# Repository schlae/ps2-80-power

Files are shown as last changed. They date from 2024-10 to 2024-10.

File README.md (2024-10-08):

# IBM PS/2 Model 80 Power Supply Schematics

There are multiple types of power supplies for these machines. This one is for the one marked 72X6665 / PEC 3978. This is the red switch 225W model.

## Notes

The design is an LLC resonant converter. It has a rather interesting auxiliary bias supply to power the PWM controller, so technically it is two supplies in one box.

* Inrush current into the main reservoir capacitors is limited by R117/118 and RT1/RT2. The capacitors are tied in series (to handle the 220V input case) with balancing resistors.
* The bias supply uses a preregulator that detects ~180V Vp-p and, partway through every AC cycle, cuts off a triac connected in series with a plain-old linear transformer isolated power supply. This ensures that the VCC bias supply has roughly the same voltage regardless of whether it is connected to 120V or 220V.
* The PWM controller is a SG3524 with external transistors that drive an isolation transformer in order to control the BJTs in the main power stage on the non-isolated side. The output voltage trim is set by R77, which samples both the +5V and +12V rail.
* An overcurrent comparator monitors the ripple current through the main power transformer and latches off the PWM controller if it exceeds a threshold. It also monitors the current *difference* between the two Schottky diodes in the 12V secondary side, presumably to detect Schottky diode failures.
* Every voltage (+12, -12V, +5V) is monitored for overvoltage and undervoltage. Overvoltages cause the supply to latch off. Undervoltage just deasserts the power good. Trimmer potentiometer R50 adjusts the voltage reference used by the comparators.
* The power LED is driven by the power good signal.
* The HDD LED is driven by a signal from the planar (motherboard).

## License
This work is licensed under Creative Commons Attribution-ShareAlike 4.0 International.
(C) 2024 Tube Time.

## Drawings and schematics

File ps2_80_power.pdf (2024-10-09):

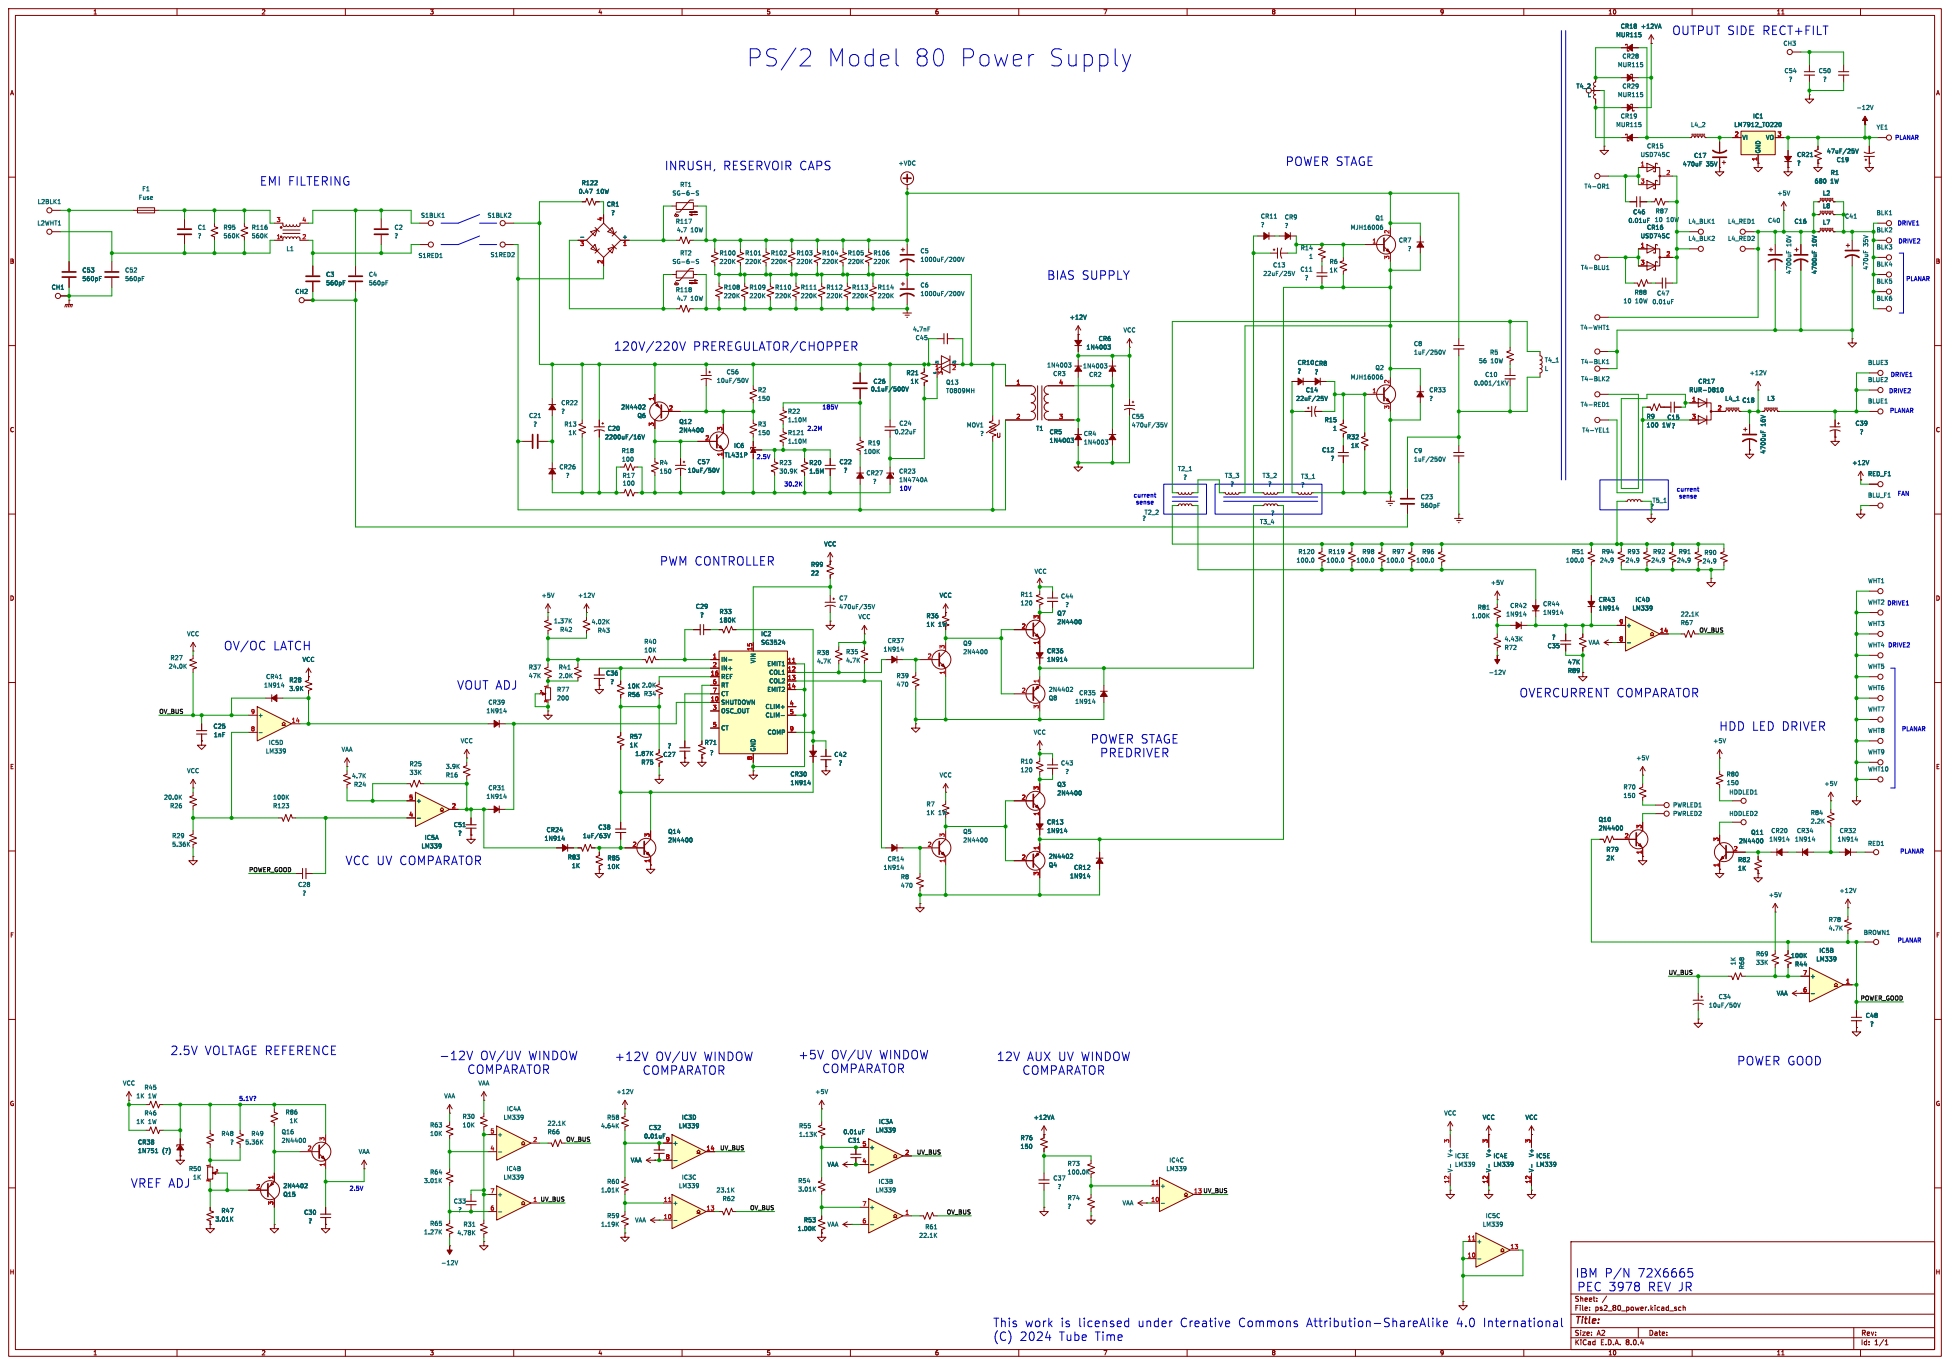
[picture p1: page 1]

OUTPUT SIDE RECT+FILT

PLANAR PS/2 Model 80 Power Supply

current sense POWER STAGE

current sense OVERCURRENT COMPARATOR VOUT ADJ

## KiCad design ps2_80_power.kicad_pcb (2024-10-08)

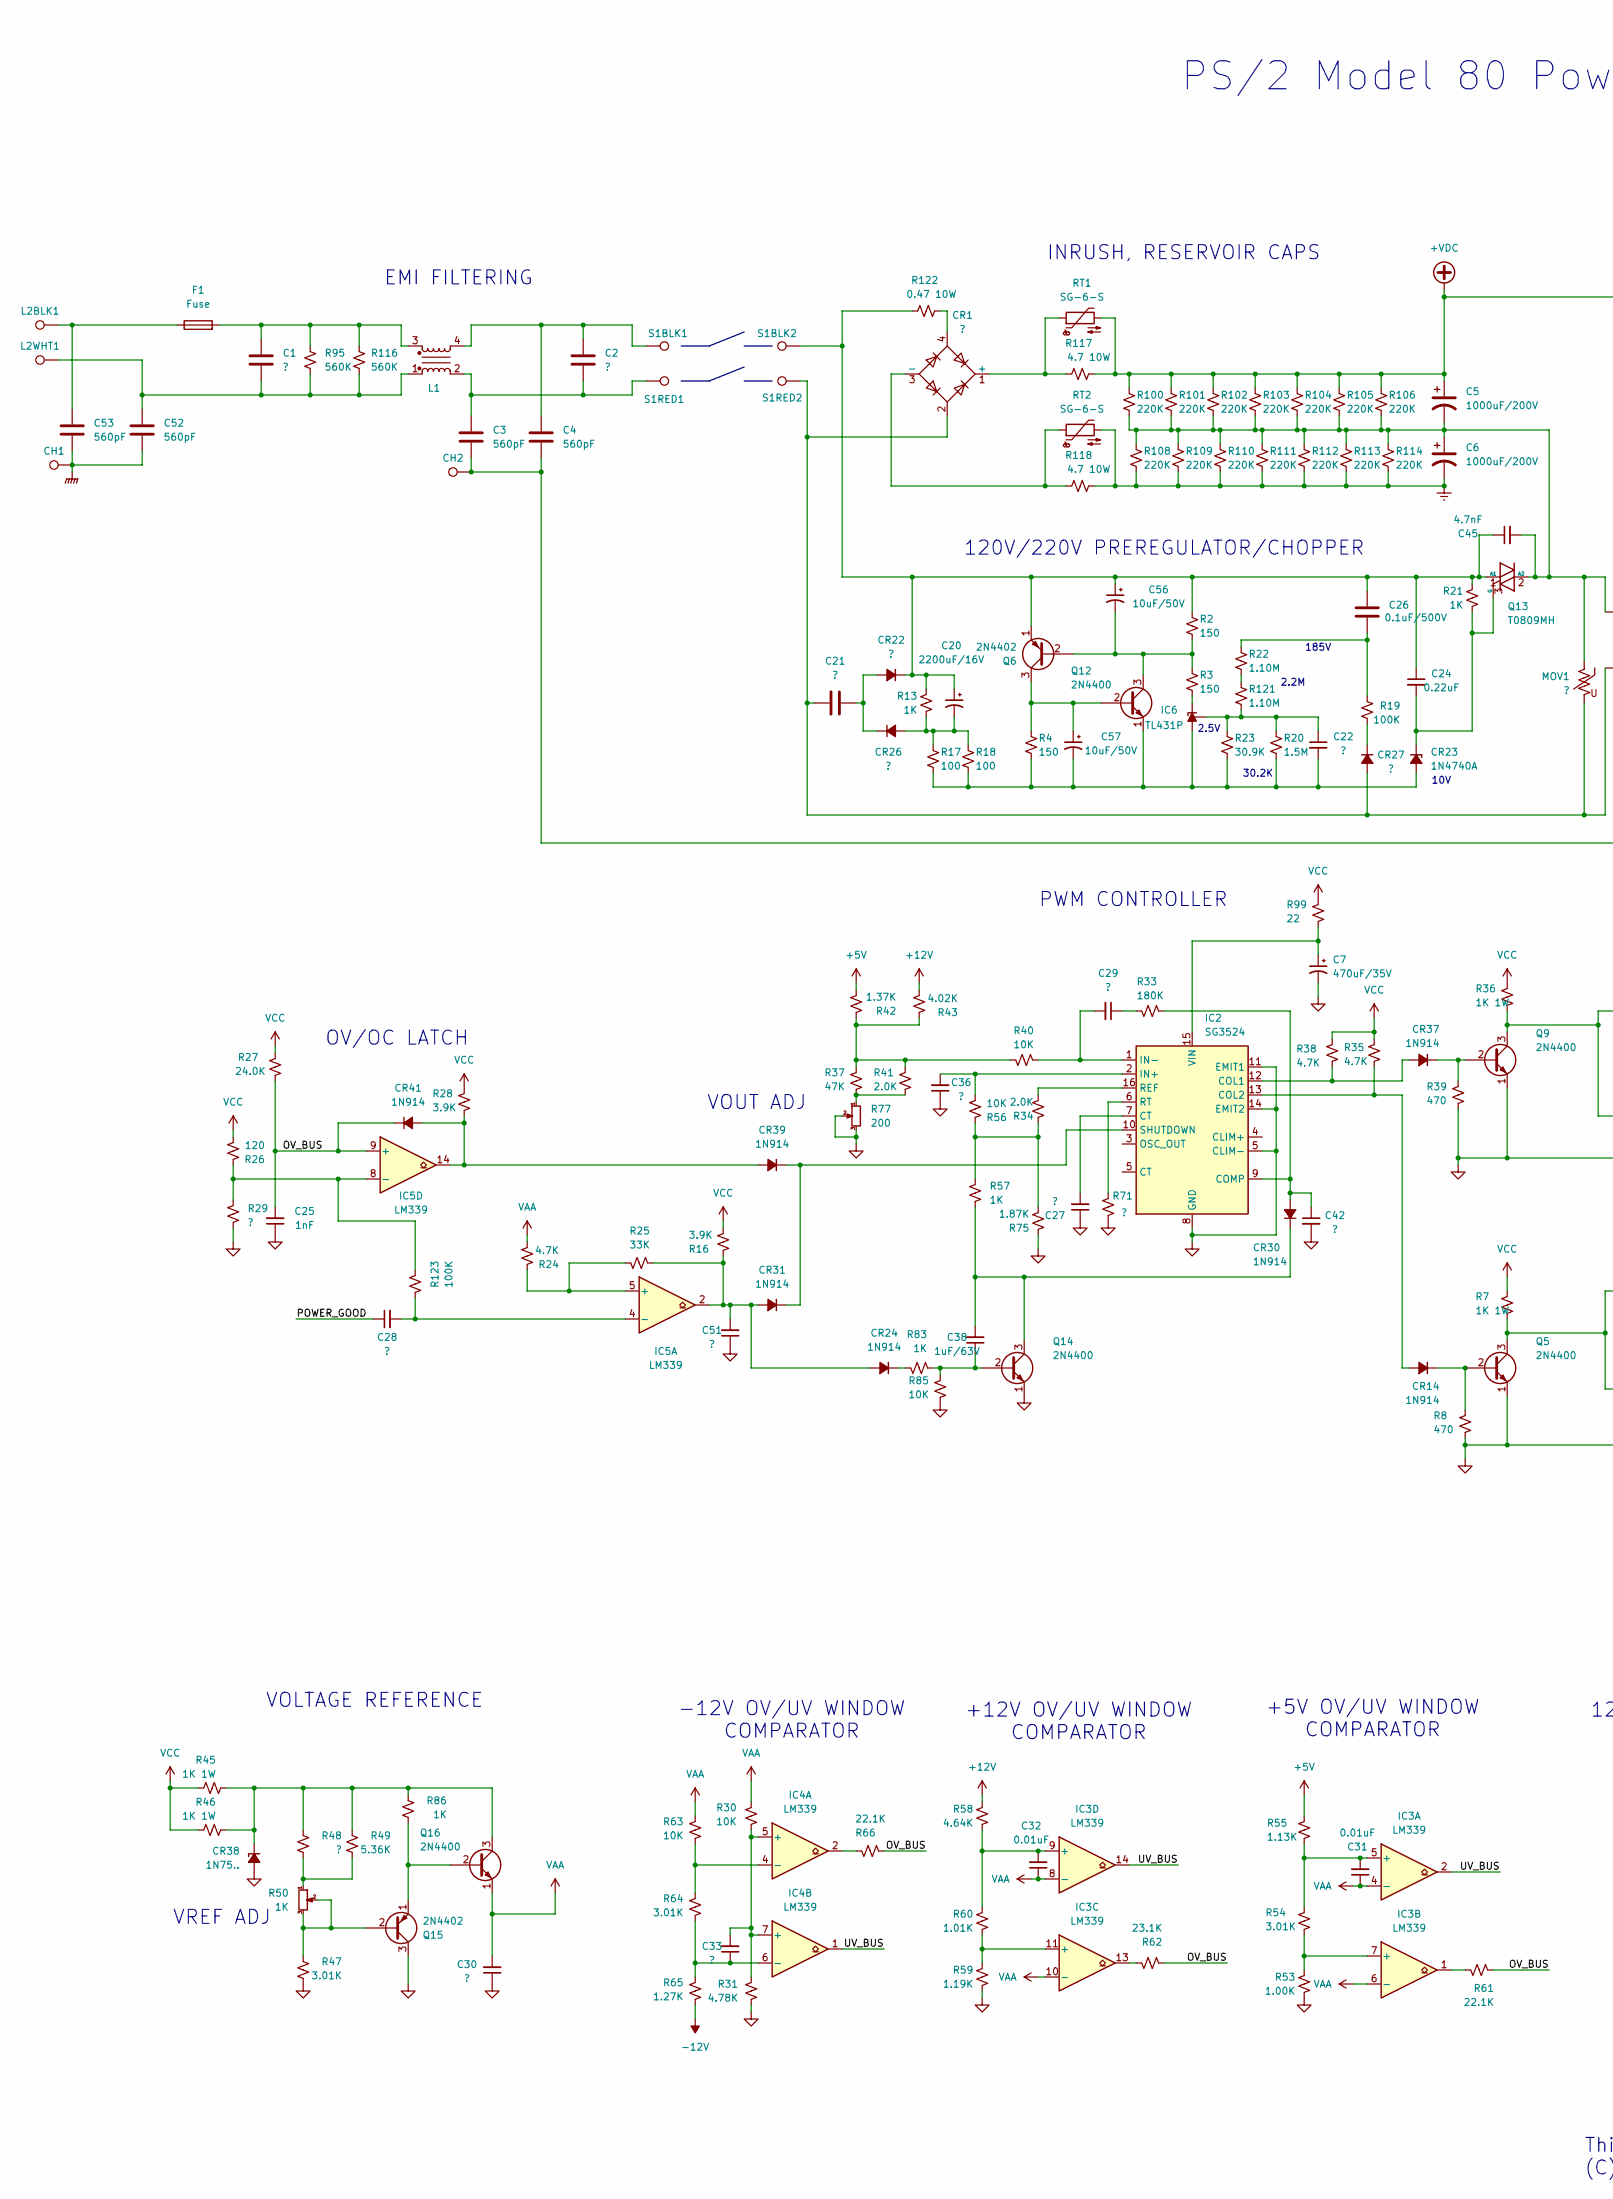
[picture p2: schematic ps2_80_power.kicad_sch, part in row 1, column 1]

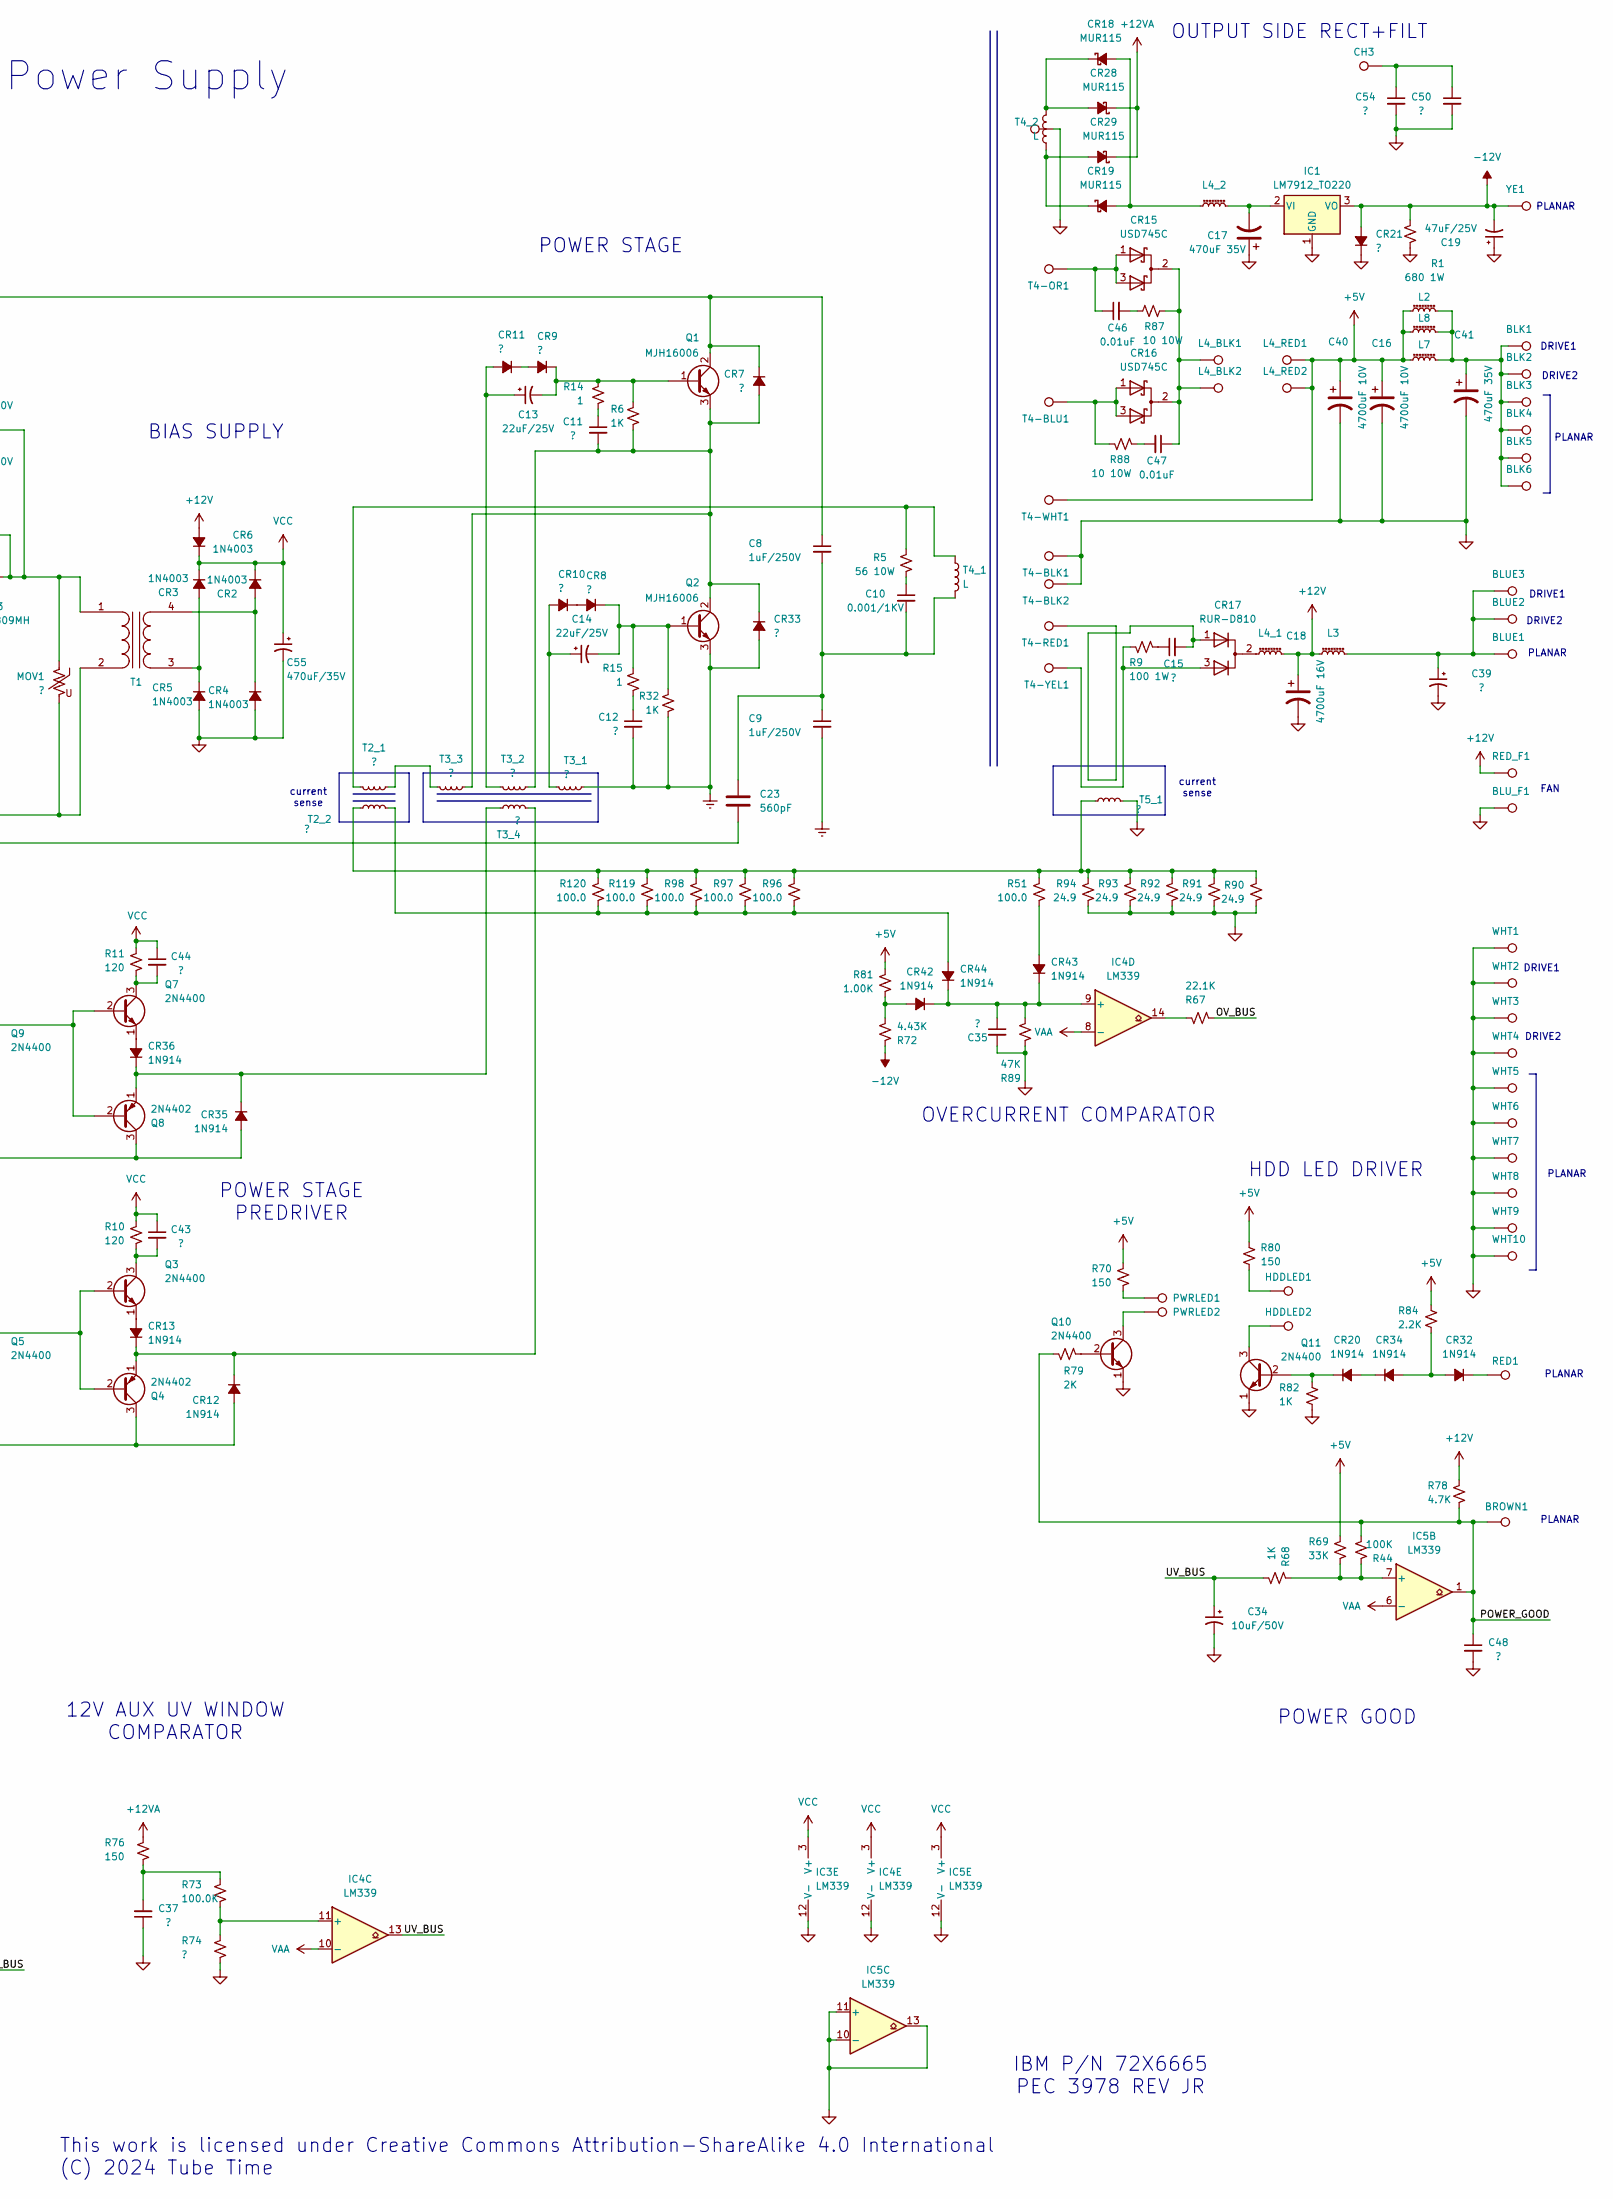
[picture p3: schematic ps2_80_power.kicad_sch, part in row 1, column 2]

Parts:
BLK1, BLK2, BLK3, BLK4, BLK5, BLK6: TestPoint; SolderWire-1sqmm_1x01_D1.4mm_OD2.7mm
BLUE1, BLUE2, BLUE3: TestPoint; SolderWire-1sqmm_1x01_D1.4mm_OD2.7mm
BLU_F1: TestPoint; SolderWire-1sqmm_1x01_D1.4mm_OD2.7mm
BROWN1: TestPoint; SolderWire-1sqmm_1x01_D1.4mm_OD2.7mm
C1, C2, C21: ?; C_Rect_L29.0mm_W12.2mm_P27.50mm_MKT
C3, C4, C23, C52, C53: 560pF; C_Disc_D12.5mm_W5.0mm_P10.00mm
C5, C6: 1000uF/200V; CP_Radial_D35.0mm_P10.00mm_SnapIn
C7, C55: 470uF/35V; CP_Radial_D13.0mm_P5.00mm
C8, C9: 1uF/250V; C_Rect_L29.0mm_W7.6mm_P27.50mm_MKT
C10: 0.001/1KV; C_Disc_D7.5mm_W5.0mm_P7.50mm
C11, C12, C22, C27, C28, C36: ?; C_Axial_L3.8mm_D2.6mm_P12.50mm_Horizontal
C13, C14: 22uF/25V; CP_Radial_D5.0mm_P2.50mm
C15, C48: ?; C_Disc_D10.5mm_W5.0mm_P7.50mm
C16, C40: 4700uF 10V; CP_Radial_D16.0mm_P7.50mm
C17, C41: 470uF 35V; CP_Radial_D13.0mm_P7.50mm
C18: 4700uF 16V; CP_Radial_D16.0mm_P7.50mm
C19: 47uF/25V; CP_Radial_D5.0mm_P2.50mm
C20: 2200uF/16V; CP_Radial_D16.0mm_P7.50mm
C24: 0.22uF; C_Axial_L3.8mm_D2.6mm_P12.50mm_Horizontal
C25: 1nF; C_Axial_L3.8mm_D2.6mm_P10.00mm_Horizontal
C26: 0.1uF/500V; C_Rect_L11.0mm_W2.8mm_P10.00mm_MKT
C29, C30, C33, C35, C37, C42, C43, C44, C51: ?; C_Axial_L3.8mm_D2.6mm_P10.00mm_Horizontal
C31, C32: 0.01uF; C_Axial_L3.8mm_D2.6mm_P7.50mm_Horizontal
C34, C56, C57: 10uF/50V; CP_Radial_D5.0mm_P2.50mm
C38: 1uF/63V; C_Rect_L7.0mm_W6.0mm_P5.00mm
C39: ?; CP_Radial_D5.0mm_P2.50mm
C45: 4.7nF; C_Axial_L3.8mm_D2.6mm_P10.00mm_Horizontal
C46, C47: 0.01uF; C_Disc_D10.5mm_W5.0mm_P7.50mm
C50: ?; C_Rect_L11.0mm_W2.8mm_P10.00mm_MKT
C54: ?; C_Disc_D7.5mm_W5.0mm_P7.50mm
CH1, CH2, CH3: TestPoint; SolderWire-2.5sqmm_1x01_D2.4mm_OD3.6mm
CR1: ?; Diode_Bridge_Vishay_KBPC1
CR2, CR3, CR4, CR5, CR6: 1N4003; D_DO-41_SOD81_P12.70mm_Horizontal
CR7, CR8, CR9, CR10, CR11, CR22, CR26, CR27, CR33: ?; D_DO-41_SOD81_P12.70mm_Horizontal
CR12, CR13, CR14, CR20, CR24, CR30, CR31, CR32, CR34, CR35, CR36, CR37, CR39, CR41, CR42, CR43, CR44: 1N914; D_DO-41_SOD81_P12.70mm_Horizontal
CR15, CR16: USD745C; TO-220-3_Vertical
CR17: RUR-D810; TO-220-3_Vertical
CR18, CR19, CR28, CR29: MUR115; D_DO-41_SOD81_P10.16mm_Horizontal
CR21: ?; D_DO-201_P15.24mm_Horizontal
CR23: 1N4740A; D_DO-41_SOD81_P12.70mm_Horizontal
CR38: 1N75..; D_DO-41_SOD81_P10.16mm_Horizontal
F1: Fuse; Fuseholder_Clip-6.3x32mm_Littelfuse_102_122_Inline_P34.21x7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
HDDLED1, HDDLED2: TestPoint; SolderWire-0.1sqmm_1x01_D0.4mm_OD1mm
IC1: LM7912_TO220; TO-220-3_Vertical
IC2: SG3524; DIP254P762X635-16
IC3, IC4, IC5: LM339; DIP254P762X635-14
IC6: TL431P; DIP-8_W7.62mm
L1: Choke_Schaffner_RN102-0.3-02-22M; Choke_Schaffner_RN102-04-14.0x14.0mm
L2, L3, L7, L8: L_Ferrite_Small; L_Axial_L11.0mm_D4.5mm_P7.62mm_Vertical_Fastron_MECC
L2BLK1, L2WHT1, L4_BLK1, L4_BLK2, L4_RED1, L4_RED2: TestPoint; SolderWire-2.5sqmm_1x01_D2.4mm_OD3.6mm
L4_1, L4_2: L_Ferrite_Small; L_Axial_L29.9mm_D14.0mm_P38.00mm_Horizontal_Vishay_IHA-105
MOV1: ?; RV_Disc_D21.5mm_W4.3mm_P10mm
PWRLED1, PWRLED2: TestPoint; SolderWire-0.1sqmm_1x01_D0.4mm_OD1mm
Q1, Q2: MJH16006; TO-247-3_Vertical
Q3, Q5, Q7, Q9, Q10, Q14, Q16: 2N4400; TO-92_Inline
Q4, Q8, Q15: 2N4402; TO-92_Inline
Q6: 2N4402; TO-92_Inline_Wide
Q11, Q12: 2N4400; TO-92_Inline_Wide
Q13: T0809MH; TO-220-3_Vertical
R1: 680 1W; R_Axial_DIN0207_L6.3mm_D2.5mm_P15.24mm_Horizontal
R2, R3, R4, R70, R76, R80: 150; R_Axial_DIN0309_L9.0mm_D3.2mm_P12.70mm_Horizontal
R5: 56 10W; R_Axial_DIN0309_L9.0mm_D3.2mm_P15.24mm_Horizontal
R6, R13, R21, R32, R57, R68, R82, R83, R86: 1K; R_Axial_DIN0309_L9.0mm_D3.2mm_P12.70mm_Horizontal
R7, R36, R45, R46: 1K 1W; R_Axial_DIN0207_L6.3mm_D2.5mm_P15.24mm_Horizontal
R8, R39: 470; R_Axial_DIN0309_L9.0mm_D3.2mm_P12.70mm_Horizontal
R9: 100 1W; R_Axial_DIN0207_L6.3mm_D2.5mm_P15.24mm_Horizontal
R10, R11: 120; R_Axial_DIN0207_L6.3mm_D2.5mm_P15.24mm_Horizontal
R14, R15: 1; R_Axial_DIN0309_L9.0mm_D3.2mm_P12.70mm_Horizontal
R16, R28: 3.9K; R_Axial_DIN0309_L9.0mm_D3.2mm_P12.70mm_Horizontal
R17, R18: 100; R_Axial_DIN0309_L9.0mm_D3.2mm_P15.24mm_Horizontal
R19, R44, R123: 100K; R_Axial_DIN0309_L9.0mm_D3.2mm_P12.70mm_Horizontal
R20: 1.5M; R_Axial_DIN0309_L9.0mm_D3.2mm_P12.70mm_Horizontal
R22, R121: 1.10M; R_Axial_DIN0309_L9.0mm_D3.2mm_P12.70mm_Horizontal
R23: 30.9K; R_Axial_DIN0309_L9.0mm_D3.2mm_P12.70mm_Horizontal
R24, R35, R38, R78: 4.7K; R_Axial_DIN0309_L9.0mm_D3.2mm_P12.70mm_Horizontal
R25, R69: 33K; R_Axial_DIN0309_L9.0mm_D3.2mm_P12.70mm_Horizontal
R26: 120; R_Axial_DIN0309_L9.0mm_D3.2mm_P12.70mm_Horizontal
R27: 24.0K; R_Axial_DIN0309_L9.0mm_D3.2mm_P12.70mm_Horizontal
R29, R48, R71, R74: ?; R_Axial_DIN0309_L9.0mm_D3.2mm_P12.70mm_Horizontal
R30, R40, R56, R63, R85: 10K; R_Axial_DIN0309_L9.0mm_D3.2mm_P12.70mm_Horizontal
R31: 4.78K; R_Axial_DIN0309_L9.0mm_D3.2mm_P12.70mm_Horizontal
R33: 180K; R_Axial_DIN0309_L9.0mm_D3.2mm_P12.70mm_Horizontal
R34, R41: 2.0K; R_Axial_DIN0309_L9.0mm_D3.2mm_P12.70mm_Horizontal
R37, R89: 47K; R_Axial_DIN0309_L9.0mm_D3.2mm_P12.70mm_Horizontal
R42: 1.37K; R_Axial_DIN0309_L9.0mm_D3.2mm_P12.70mm_Horizontal
R43: 4.02K; R_Axial_DIN0309_L9.0mm_D3.2mm_P12.70mm_Horizontal
R47, R54, R64: 3.01K; R_Axial_DIN0309_L9.0mm_D3.2mm_P12.70mm_Horizontal
R49: 5.36K; R_Axial_DIN0309_L9.0mm_D3.2mm_P12.70mm_Horizontal
R50: 1K; Potentiometer_Bourns_3386C_Horizontal
R51, R96, R97, R98, R119, R120: 100.0; R_Axial_DIN0309_L9.0mm_D3.2mm_P12.70mm_Horizontal
R53, R81: 1.00K; R_Axial_DIN0309_L9.0mm_D3.2mm_P12.70mm_Horizontal
R55: 1.13K; R_Axial_DIN0309_L9.0mm_D3.2mm_P12.70mm_Horizontal
R58: 4.64K; R_Axial_DIN0309_L9.0mm_D3.2mm_P12.70mm_Horizontal
R59: 1.19K; R_Axial_DIN0309_L9.0mm_D3.2mm_P12.70mm_Horizontal
R60: 1.01K; R_Axial_DIN0309_L9.0mm_D3.2mm_P12.70mm_Horizontal
R61, R66, R67: 22.1K; R_Axial_DIN0309_L9.0mm_D3.2mm_P12.70mm_Horizontal
R62: 23.1K; R_Axial_DIN0309_L9.0mm_D3.2mm_P12.70mm_Horizontal
R65: 1.27K; R_Axial_DIN0309_L9.0mm_D3.2mm_P12.70mm_Horizontal
R72: 4.43K; R_Axial_DIN0309_L9.0mm_D3.2mm_P12.70mm_Horizontal
R73: 100.0K; R_Axial_DIN0309_L9.0mm_D3.2mm_P12.70mm_Horizontal
R75: 1.87K; R_Axial_DIN0309_L9.0mm_D3.2mm_P12.70mm_Horizontal
R77: 200; Potentiometer_Bourns_3386C_Horizontal
R79: 2K; R_Axial_DIN0309_L9.0mm_D3.2mm_P12.70mm_Horizontal
R84: 2.2K; R_Axial_DIN0309_L9.0mm_D3.2mm_P12.70mm_Horizontal
R87, R88: 10 10W; R_Axial_DIN0309_L9.0mm_D3.2mm_P15.24mm_Horizontal
R90, R91, R92, R93, R94: 24.9; R_Axial_DIN0309_L9.0mm_D3.2mm_P12.70mm_Horizontal
R95, R116: 560K; R_Axial_DIN0309_L9.0mm_D3.2mm_P15.24mm_Horizontal
R99: 22; R_Axial_DIN0309_L9.0mm_D3.2mm_P12.70mm_Horizontal
R100, R101, R102, R103, R104, R105, R106, R108, R109, R110, R111, R112, R113, R114: 220K; R_Axial_DIN0309_L9.0mm_D3.2mm_P15.24mm_Horizontal
R117, R118: 4.7 10W; R_Axial_DIN0309_L9.0mm_D3.2mm_P15.24mm_Horizontal
R122: 0.47 10W; R_Axial_DIN0309_L9.0mm_D3.2mm_P15.24mm_Horizontal
RED1: TestPoint; SolderWire-1sqmm_1x01_D1.4mm_OD2.7mm
RED_F1: TestPoint; SolderWire-1sqmm_1x01_D1.4mm_OD2.7mm
RT1, RT2: SG-6-S
S1BLK1, S1BLK2, S1RED1, S1RED2: TestPoint; SolderWire-2.5sqmm_1x01_D2.4mm_OD3.6mm
T1: Transformer_1P_1S; Transformer_Toroid_Horizontal_D14.0mm_Amidon-T50
T2_1, T3_3: ?; C_Rect_L16.5mm_W4.7mm_P15.00mm_MKT
T2_2, T5_1: ?; C_Rect_L9.0mm_W2.5mm_P7.50mm_MKT
T3_1, T3_2, T3_4: ?; C_Rect_L7.0mm_W3.5mm_P5.00mm
T4-BLK1, T4-BLK2, T4-BLU1, T4-OR1, T4-RED1, T4-WHT1, T4-YEL1: TestPoint; SolderWire-2.5sqmm_1x01_D2.4mm_OD3.6mm
T4_1: L; C_Rect_L24.0mm_W7.0mm_P22.50mm_MKT
T4_2: L; C_Rect_L19.0mm_W9.0mm_P15.00mm_MKS4
T4_2A1: TestPoint; SolderWire-0.75sqmm_1x01_D1.25mm_OD2.3mm
WHT1, WHT2, WHT3, WHT4, WHT5, WHT6, WHT7, WHT8, WHT9, WHT10: TestPoint; SolderWire-1sqmm_1x01_D1.4mm_OD2.7mm
YE1: TestPoint; SolderWire-1sqmm_1x01_D1.4mm_OD2.7mm

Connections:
+5V: C16.1, C40.1, L2.1, L4_RED1.1, L4_RED2.1, L7.1, L8.1, R42.1, R55.2, R69.2, R70.2, R80.2, R81.1, R84.1, T4-WHT1.1
+12V: C18.1, CR6.2 (A), L3.1, L4_1.2, R43.1, R58.1, R78.2, RED_F1.1
+12VA: CR28.1 (K), CR29.1 (K), R76.2
+VDC: C5.1, C8.1, CR7.1 (K), Q1.2 (C), R100.1, R101.1, R102.1, R103.1, R104.1, R105.1, R106.1, R117.2, RT1.2
-12V: C19.2, CR21.2 (A), IC1.3 (VO), R1.1, R65.2, R72.1, YE1.1
/OV_BUS: C25.2, CR41.1 (K), IC5.9 (+), R27.1, R61.2, R62.2, R66.1, R67.1
/POWER_GOOD: BROWN1.1, C28.1, C48.1, IC5.1, R44.1, R78.1, R79.2
/UV_BUS: C34.1, IC3.2, IC3.14, IC4.1, IC4.13, R68.1
Earth: C6.2, C9.2, C12.2, CR33.2 (A), Q2.3 (E), R32.2, R108.2, R109.2, R110.2, R111.2, R112.2, R113.2, R114.2, R118.2, RT2.2, T3_1.1
GND: BLU_F1.1, C7.2, C16.2, C17.1, C18.2, C19.1, C25.1, C27.1, C30.1, C34.2, C35.2, C36.1, C37.1, C39.2, C40.2, C41.2, C42.2, C48.2, C50.2, C51.1, C54.2, C55.2, CR4.2 (A), CR5.2 (A), CR12.2 (A), CR21.1 (K), CR35.2 (A), CR38.2 (A), IC1.1 (GND), IC2.5 (CLIM-), IC2.8 (GND), IC2.11 (EMIT1), IC2.14 (EMIT2), IC3.12 (V-), IC4.12 (V-), IC5.10 (-), IC5.11 (+), IC5.12 (V-), IC5.13, Q4.3 (C), Q5.1 (E), Q8.3 (C), Q9.1 (E), Q10.1 (E), Q11.1 (E), Q14.1 (E), Q15.3 (C), R1.2, R8.1, R29.1, R31.2, R39.1, R47.1, R53.2, R59.2, R71.2, R74.1, R75.2, R77.2, R77.3, R82.2, R85.1, R89.1, R90.2, R91.2, R92.2, R93.2, R94.2, T4-BLK1.1, T4-BLK2.1, T4_2A1.1, T5_1.1, WHT1.1, WHT2.1, WHT3.1, WHT4.1, WHT5.1, WHT6.1, WHT7.1, WHT8.1, WHT9.1, WHT10.1
GNDPWR: C52.2, C53.2, CH1.1
unnamed: BLK1.1, BLK2.1, BLK3.1, BLK4.1, BLK5.1, BLK6.1, C41.1, L2.2, L7.2, L8.2
unnamed: BLUE1.1, BLUE2.1, BLUE3.1, C39.1, L3.2
unnamed: C1.1, F1.2, L1.3, R95.1, R116.1
unnamed: C1.2, C52.1, L1.1, L2WHT1.1, R95.2, R116.2
unnamed: C2.1, C4.1, L1.4, S1BLK1.1
unnamed: C2.2, C3.1, L1.2, S1RED1.1
unnamed: C10.1, R5.1
unnamed: C8.2, C9.1, C10.2, C23.2, T4_1.2
unnamed: C11.1, R14.2
unnamed: C12.1, R15.2
unnamed: C15.1, R9.1
unnamed: C15.2, CR17.1 (K), T4-RED1.1
unnamed: C3.2, C4.2, C23.1, CH2.1
unnamed: C26.2, R19.2, R22.1
unnamed: C27.2, IC2.7 (CT)
unnamed: C29.1, R33.2
unnamed: C37.2, R73.2, R76.1
unnamed: C46.1, CR15.1 (K), CR15.3 (K), T4-OR1.1
unnamed: C46.2, R87.1
unnamed: C47.2, R88.1
unnamed: C50.1, C54.1, CH3.1
unnamed: C53.1, F1.1, L2BLK1.1
unnamed: CR1.1 (+), R117.1, RT1.1
unnamed: CR1.3 (-), R118.1, RT2.1
unnamed: CR1.4, R122.2
unnamed: CR2.2 (A), CR4.1 (K), T1.4 (SB)
unnamed: CR3.2 (A), CR5.1 (K), T1.3 (SA)
unnamed: C14.2, CR8.1 (K), Q2.1 (B), R15.1, R32.1
unnamed: C13.2, CR9.1 (K), Q1.1 (B), R6.1, R14.1
unnamed: C14.1, CR10.2 (A), T3_1.2
unnamed: CR8.2 (A), CR10.1 (K)
unnamed: C13.1, CR11.2 (A), T3_2.2
unnamed: CR9.2 (A), CR11.1 (K)
unnamed: CR12.1 (K), CR13.1 (K), Q4.1 (E), T3_4.2
unnamed: CR13.2 (A), Q3.1 (E)
unnamed: CR14.2 (A), IC2.13 (COL2), R35.1
unnamed: CR14.1 (K), Q5.2 (B), R8.2
unnamed: C47.1, CR15.2 (A), CR16.2 (A), L4_BLK1.1, L4_BLK2.1, R87.2
unnamed: CR16.1 (K), CR16.3 (K), R88.2, T4-BLU1.1
unnamed: CR17.2 (A), L4_1.1
unnamed: CR17.3 (K), R9.2, T4-YEL1.1
unnamed: CR18.2 (A), CR19.2 (A), L4_2.1
unnamed: CR18.1 (K), CR28.2 (A), T4_2.1
unnamed: CR19.1 (K), CR29.2 (A), T4_2.2
unnamed: CR20.2 (A), CR34.1 (K)
unnamed: CR20.1 (K), Q11.2 (B), R82.1
unnamed: C21.2, CR22.2 (A), CR26.1 (K)
unnamed: C20.1, C24.1, C26.1, C45.1, C56.1, CR22.1 (K), Q6.1 (E), Q13.1 (A1), R2.1, R13.1, R21.1, R122.1, S1BLK2.1
unnamed: C22.2, C57.2, CR23.2 (A), IC6.6 (A), Q12.1 (E), R4.2, R17.2, R18.2, R20.2, R23.2
unnamed: C24.2, CR23.1 (K), Q13.3 (G), R21.2
unnamed: C51.2, CR24.2 (A), CR31.2 (A), IC5.2, R16.1, R25.2
unnamed: CR24.1 (K), R83.1
unnamed: C20.2, CR26.2 (A), R13.2, R17.1, R18.1
unnamed: C21.1, CR1.2, CR27.2 (A), MOV1.2, S1RED2.1, T1.2 (AB)
unnamed: CR27.1 (K), R19.1
unnamed: C42.1, CR30.2 (A), IC2.9 (COMP), R33.1
unnamed: C38.2, CR30.1 (K), Q14.3 (C), R57.1
unnamed: CR31.1 (K), CR39.1 (K), IC2.10 (SHUTDOWN)
unnamed: CR32.2 (A), CR34.2 (A), R84.2
unnamed: CR32.1 (K), RED1.1
unnamed: C11.2, CR7.2 (A), CR33.1 (K), Q1.3 (E), Q2.2 (C), R6.2, T3_2.1, T3_3.1
unnamed: CR35.1 (K), CR36.1 (K), Q8.1 (E), T3_4.1
unnamed: CR36.2 (A), Q7.1 (E)
unnamed: CR37.2 (A), IC2.12 (COL1), R38.1
unnamed: CR37.1 (K), Q9.2 (B), R39.2
unnamed: CR38.1 (K), Q16.3 (C), R45.2, R46.2, R48.2, R49.2, R86.2
unnamed: CR39.2 (A), CR41.2 (A), IC5.14, R28.1
unnamed: CR42.2 (A), R72.2, R81.2
unnamed: C35.1, CR42.1 (K), CR43.1 (K), CR44.1 (K), IC4.9 (+), R89.2
unnamed: CR43.2 (A), R51.2
unnamed: CR44.2 (A), R96.2, R97.2, R98.2, R119.2, R120.2, T2_2.1
unnamed: HDDLED1.1, R80.1
unnamed: C17.2, IC1.2 (VI), L4_2.2
unnamed: C36.2, IC2.2 (IN+), R56.1
unnamed: C29.2, IC2.1 (IN-), R40.1
unnamed: IC2.16 (REF), R34.1
unnamed: IC2.6 (RT), R71.1
unnamed: C7.1, IC2.15 (VIN), R99.1
unnamed: IC3.1, R61.1
unnamed: IC3.13, R62.1
unnamed: C31.2, IC3.5 (+), R54.2, R55.1
unnamed: IC3.7 (+), R53.1, R54.1
unnamed: IC3.11 (+), R59.1, R60.2
unnamed: C32.2, IC3.9 (+), R58.2, R60.1
unnamed: IC4.2, R66.2
unnamed: IC4.14, R67.2
unnamed: C33.2, IC4.5 (+), IC4.7 (+), R30.2, R31.1
unnamed: IC4.4 (-), R63.2, R64.1
unnamed: C33.1, IC4.6 (-), R64.2, R65.1
unnamed: IC4.11 (+), R73.1, R74.2
unnamed: IC5.5 (+), R24.2, R25.1
unnamed: C28.2, IC5.4 (-), R123.1
unnamed: IC5.7 (+), R44.2, R68.2, R69.1
unnamed: IC5.8 (-), R26.2, R29.2, R123.2
unnamed: IC6.1 (K), R3.2
unnamed: C22.1, IC6.8 (REF), R20.1, R23.1, R121.2
unnamed: PWRLED1.1, R70.1
unnamed: Q3.2 (B), Q4.2 (B), Q5.3 (C), R7.1
unnamed: C43.2, Q3.3 (C), R10.1
unnamed: Q7.2 (B), Q8.2 (B), Q9.3 (C), R36.1
unnamed: C44.2, Q7.3 (C), R11.1
unnamed: Q10.2 (B), R79.1
unnamed: PWRLED2.1, Q10.3 (C)
unnamed: HDDLED2.1, Q11.3 (C)
unnamed: C57.1, Q6.3 (C), Q12.2 (B), R4.1
unnamed: C56.2, Q6.2 (B), Q12.3 (C), R2.2, R3.1
unnamed: C5.2, C6.1, C45.2, MOV1.1, Q13.2 (A2), R100.2, R101.2, R102.2, R103.2, R104.2, R105.2, R106.2, R108.1, R109.1, R110.1, R111.1, R112.1, R113.1, R114.1, T1.1 (AA)
unnamed: C38.1, Q14.2 (B), R83.2, R85.2
unnamed: Q15.2 (B), R47.2, R50.2, R50.3
unnamed: Q15.1 (E), Q16.2 (B), R86.1
unnamed: R5.2, T2_1.1, T4_1.1
unnamed: R34.2, R56.2, R57.2, R75.1
unnamed: R37.1, R41.1, R77.1
unnamed: R37.2, R40.2, R41.2, R42.2, R43.2
unnamed: R48.1, R49.1, R50.1
unnamed: R51.1, R90.1, R91.1, R92.1, R93.1, R94.1, R96.1, R97.1, R98.1, R119.1, R120.1, T2_2.2, T5_1.2
unnamed: R22.2, R121.1
unnamed: T2_1.2, T3_3.2
VAA: C30.2, C31.1, C32.1, IC3.4 (-), IC3.6 (-), IC3.8 (-), IC3.10 (-), IC4.8 (-), IC4.10 (-), IC5.6 (-), Q16.1 (E), R24.1, R30.1, R63.1
VCC: C43.1, C44.1, C55.1, CR2.1 (K), CR3.1 (K), CR6.1 (K), IC3.3 (V+), IC4.3 (V+), IC5.3 (V+), R7.2, R10.2, R11.2, R16.2, R26.1, R27.2, R28.2, R35.2, R36.2, R38.2, R45.1, R46.1, R99.2

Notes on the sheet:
PLANAR
DRIVE1
POWER GOOD
+5V OV/UV WINDOW COMPARATOR
10V
2.2M
12V AUX UV WINDOW COMPARATOR
OVERCURRENT COMPARATOR
2.5V
DRIVE2
OUTPUT SIDE RECT+FILT
current sense
FAN
POWER STAGE PREDRIVER
+12V OV/UV WINDOW COMPARATOR
HDD LED DRIVER
-12V OV/UV WINDOW COMPARATOR
120V/220V PREREGULATOR/CHOPPER
OV/OC LATCH
This work is licensed under Creative Commons Attribution-ShareAlike 4.0 International (C) 2024 Tube Time
VOUT ADJ
VREF ADJ
INRUSH, RESERVOIR CAPS
PS/2 Model 80 Power Supply
VOLTAGE REFERENCE
185V
EMI FILTERING
PWM CONTROLLER
30.2K
POWER STAGE
BIAS SUPPLY
IBM P/N 72X6665 PEC 3978 REV JR

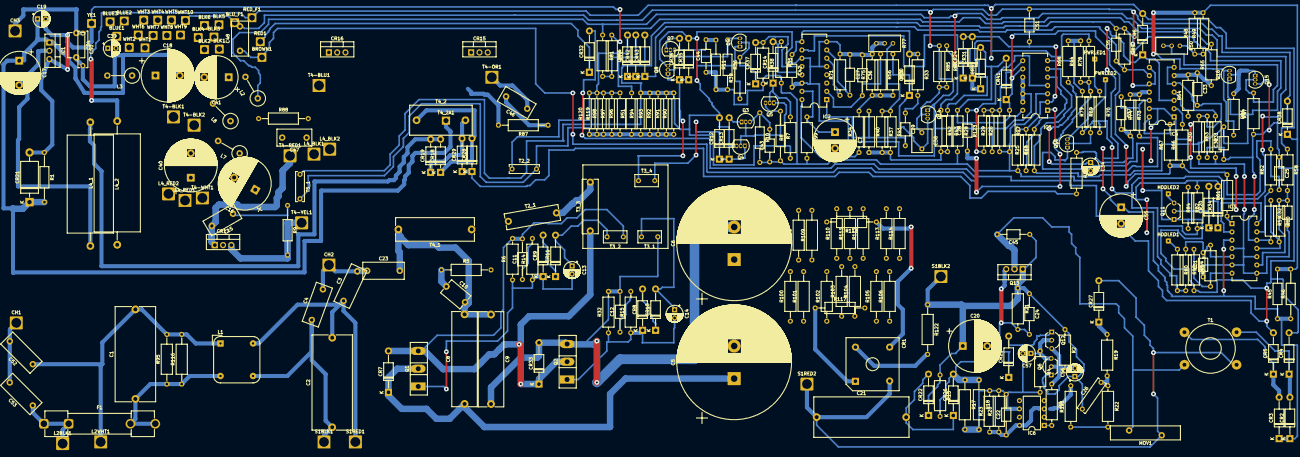
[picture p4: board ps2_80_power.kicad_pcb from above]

Board: 2 copper layers, 307 parts (0 on the bottom side), 131 nets.
